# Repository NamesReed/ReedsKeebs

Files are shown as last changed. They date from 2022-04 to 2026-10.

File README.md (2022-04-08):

# ReedsKeebs
This repository contains all working firmware for my boards and design files I have made public.  

Join my discord for help: https://discord.gg/JtBQ8nmr7R

If you have a ProMicro or similar, you will find instructions for flashing within the Alish40 QMK Firmware directory.

# KMK firmware is officially supported on the KB2040, to change your keymap, you must edit a text file, this can be done on the fly and does not require reflashing.

If you have a KB2040 and an Alish board, you can find the QMK/Vial install guide within the QMK Firmware directory.

If you have a KB2040 and an Alish board, You can find the install guide within the KMK Firmware directory.  
### To boil it down simply, the QMK/Vial KB2040 firmware is experimental, and not officially supported. This grants you the use of changing your keymap with the Vial GUI. 
## Use QMK KB2040 at your own risk.

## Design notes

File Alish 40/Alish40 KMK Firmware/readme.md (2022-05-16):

## If you have a KB2040 and an Alish board, follow these instructions for installation of KMK firmware.

1. Plug KB2040 DIRECTLY into your computer, USB hubs can cause issues.
2. Download the CircuitPython installer, a .UF2 file, from https://circuitpython.org/board/adafruit_kb2040/
3. Enter Bootloader mode on the KB2040 by pressing and holding the BOOT button then pressing the RST button.
4. The KB2040 should reboot. You will then find it in your storage devices labeled RP2 BOOT / RPI-RP2.
5. Copy and paste the .UF2 file from earlier into the RPI-RP2 device.
6. The device should reboot and will appear in your storage devices as CIRCUITPY.
7. Download the kmk_firmware repository, found here: https://github.com/KMKfw/kmk_firmware by clicking the green "Code" button, and downloading the .zip.
8. Unzip the folder using your preferred program.
9. Drag the folder titled "kmk", NOT THE ENTIRE MASTER DIRECTORY, to the CIRCUITPY drive.
10. Drag the "boot.py" file to the CIRCUITPY drive.
11. Download this repository just like you did the kmk_firmware repo, and proceed to unzip the folder.
12. Drag the "main.py" file located within the AlishKMKFirmware folder to the CIRCUITPY drive, this should be on the same level as the boot.py file, not within the kmk folder.
13. Congratulations, you now have a fully functional KB2040.

Github won't allow me to just upload the files you need, so unfortunately you need to download the entire KMK repo.

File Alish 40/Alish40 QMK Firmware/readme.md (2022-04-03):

# Follow these instructions if you want a gui to change your keymap!

# Use the .hex if you have a pro micro, use the uf2 if you have a kb2040
Scroll to the bottom for KB2040 Vial firmware instructions

### This installation will provide you the ability to change your keymap on the fly without reflashing with the use of Vial, a VIA alternative.

1. Download this repository by going back to the main page, and clicking the green "Code" button, then downloading as .zip.
2. Unzip the file using whatever software you like, 7ZIP, WinRar, ect.
3. Download QMK Toolbox at this link, https://github.com/qmk/qmk_toolbox/releases 
4. Find the latest release, the file should look something like "qmk_toolbox.exe"
5. Now, plug your pro micro into your computer, DO NOT USE A USB HUB.
6. Find the reedskeebs_alish_vial.hex within QMK toolbox under the Local Files section.
7. Check the "Auto Flash" button.
8. Select the MCU as "atmega32u4" if it is not already.
9. At this point, QMK Toolbox should be properly configured, and look like this

9. Now, locate the RST and GND pins on the pro micro.



10. Short the RST and GND pins using a paperclip, tweezers, or something similiar.
11. This puts the Pro Micro into bootloader mode, and automatically starts flashing the firmware.
12. It should now look like this if flashed successfully 



13. If it did not flash, retry shorting the pins, sometimes it takes a few tries.
15. Congrats! You can now continue with the rest of the build.

## KB2040 Vial Firmware Instructions

If you have a KB2040 and would like Vial, read this guide

Download the Vial_Alish_KB2040 ONLY IF YOU HAVE A KB2040 Hold down the BOOT button on your KB2040, then press the Reset button. This puts the board into bootloader, you should see a new "drive" on your computer labeled something like "UF2 Bootloader" Drag the Vial_Alish_KB2040.uf2 file to the new drive.

Wait a few moments, now your KB2040 is flashed with Vial firmware, easily change your keymap by downloading the Vial gui.

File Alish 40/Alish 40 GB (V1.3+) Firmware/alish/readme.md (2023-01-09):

# reedskeebs/alish

reedskeebs/alish

*A short description of the keyboard/project*

* Keyboard Maintainer: [Kyle McCreery](https://github.com/kylemccreery)
* Hardware Supported: *The PCBs, controllers supported*
* Hardware Availability: *Links to where you can find this hardware*

Make example for this keyboard (after setting up your build environment):

    make reedskeebs/alish:default

Flashing example for this keyboard:

    make reedskeebs/alish:default:flash

See the [build environment setup](https://docs.qmk.fm/#/getting_started_build_tools) and the [make instructions](https://docs.qmk.fm/#/getting_started_make_guide) for more information. Brand new to QMK? Start with our [Complete Newbs Guide](https://docs.qmk.fm/#/newbs).

## Bootloader

Enter the bootloader in 3 ways:

* **Bootmagic reset**: Hold down the key at (0,0) in the matrix (usually the top left key or Escape) and plug in the keyboard
* **Physical reset button**: Briefly press the button on the back of the PCB - some may have pads you must short instead
* **Keycode in layout**: Press the key mapped to `RESET` if it is available

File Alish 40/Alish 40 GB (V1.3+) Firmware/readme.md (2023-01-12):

# Follow these instructions if you want a gui to change your keymap!

### This installation will provide you the ability to change your keymap on the fly without reflashing with the use of VIA.

Save the [reedskeebs_alish_via.hex](https://github.com/NamesReed/ReedsKeebs/raw/main/Alish%2040/Alish%2040%20GB%20(V1.3%2B)%20Firmware/reedskeebs_alish_via.hex) to your computer. Remember where you put it.

## Windows/MacOS
1. Download and install [the latest release of QMK Toolbox using this link](https://github.com/qmk/qmk_toolbox/releases).
2. Find the latest release, the file should look something like "qmk_toolbox.exe"
3. Now, plug your pro micro into your computer, DO NOT USE A USB HUB.
4. Find the reedskeebs_alish_via.hex within QMK toolbox under the Local Files section.
5. Check the "Auto Flash" button.
6. Select the MCU as "atmega32u4" if it is not already.
7. At this point, QMK Toolbox should be properly configured, and look like this

8. Now, locate the RST and GND pins on the pro micro.



9. Short the RST and GND pins using a paperclip, tweezers, or something similiar.
10. This puts the Pro Micro into bootloader mode, and automatically starts flashing the firmware.
11. It should now look like this if flashed successfully 



12. If it did not flash, retry shorting the pins, sometimes it takes a few tries.
## Linux
1. Follow steps 2 and 3 of [the QMK setup instructions linked here](https://docs.qmk.fm/#/newbs_getting_started) to install all prerequisites and flashing tools.
2. Plug your pro micro into your computer, DO NOT USE A USB HUB.
3. Run the command `qmk flash /path/to/reedskeebs_alish_via.hex`.
4. When prompted, short the RST and GND pins using a paperclip, tweezers, or something similiar.

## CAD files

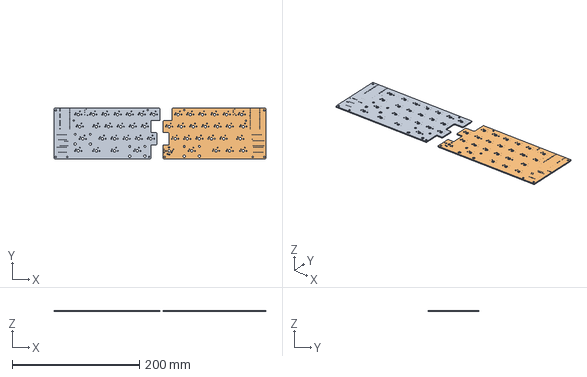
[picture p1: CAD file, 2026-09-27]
Diomedes/Cad Files/Diomedes Full.step
333.4 x 79.8 x 1.51 mm
Diomedes Full-unsaved-export-oQOao5_PCB_1
Diomedes Full-unsaved-export-oQOao5_PCB_2

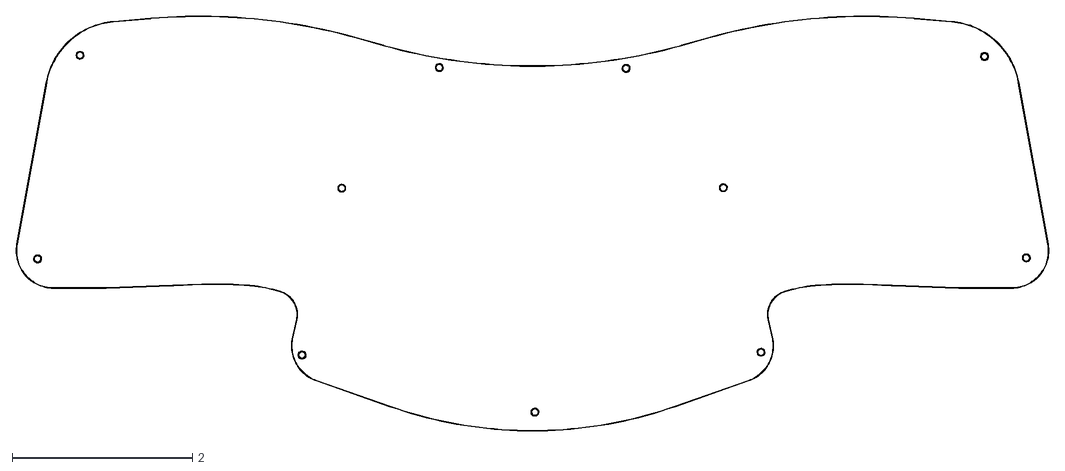
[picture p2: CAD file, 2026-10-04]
Waxwing/Waxwing Prod Files/DXF's/Waxwing_Bottom.dxf
11.5 x 4.60

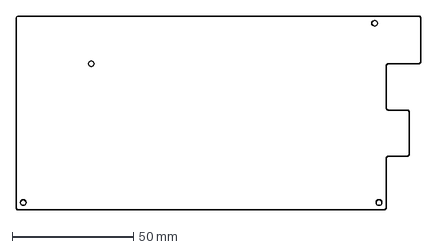
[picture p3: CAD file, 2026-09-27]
Diomedes/Cad Files/DiomedesBottomL.dxf
166.7 x 79.8 mm

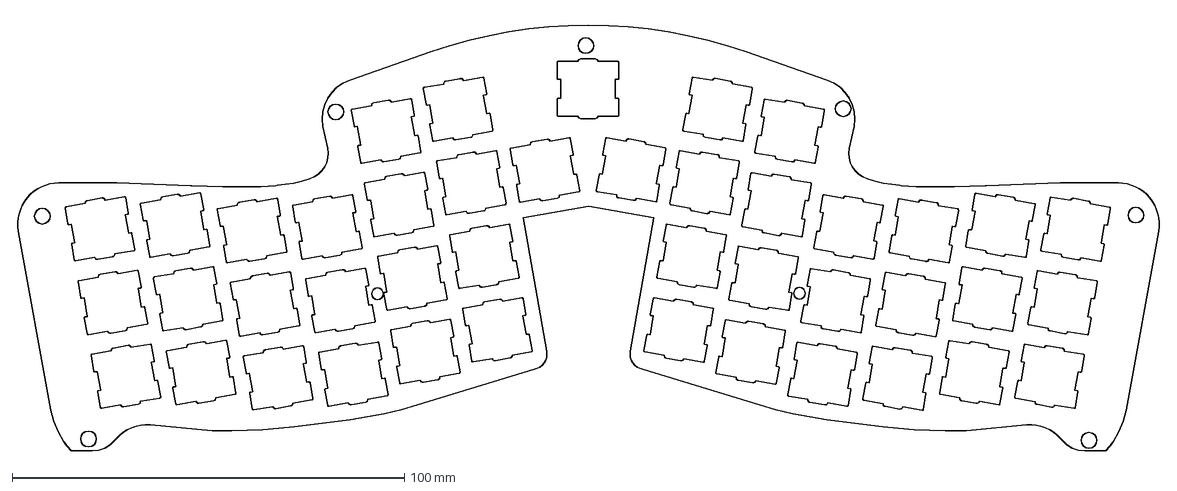
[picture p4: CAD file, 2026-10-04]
Waxwing/Waxwing Prod Files/DXF's/Waxwing_Plate_V3.dxf
291.8 x 110.8 mm

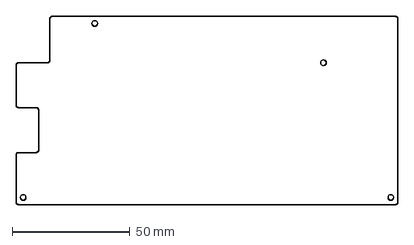
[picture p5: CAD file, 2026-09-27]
Diomedes/Cad Files/DiomedesBottomR.dxf
161.9 x 79.8 mm

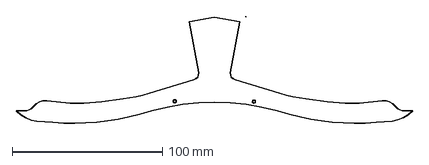
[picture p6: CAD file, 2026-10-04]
Waxwing/Waxwing Prod Files/DXF's/Waxwing_Window_V1.dxf
263.9 x 72.4 mm

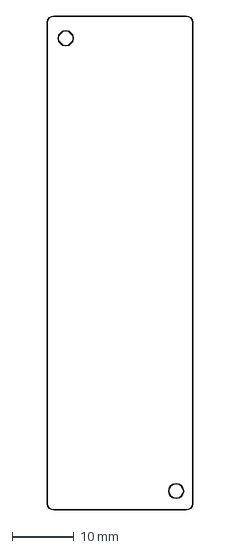
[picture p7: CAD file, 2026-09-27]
Diomedes/Cad Files/Diomedes Window.dxf
23.5 x 79.8 mm

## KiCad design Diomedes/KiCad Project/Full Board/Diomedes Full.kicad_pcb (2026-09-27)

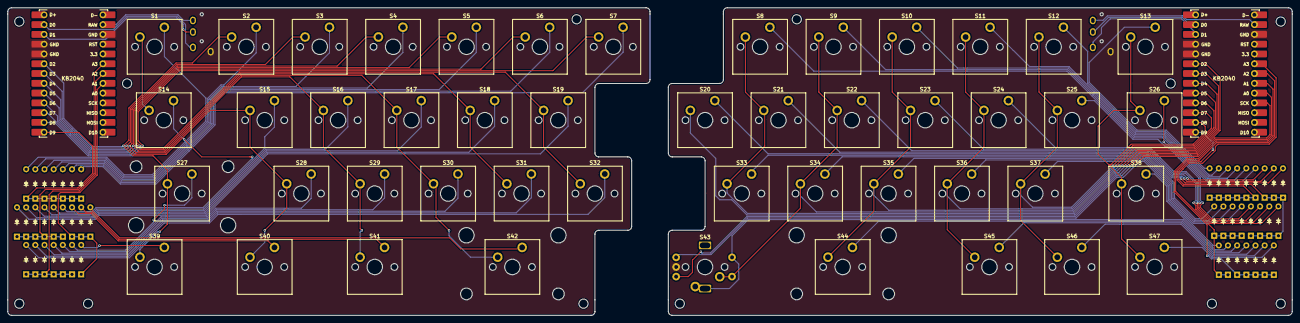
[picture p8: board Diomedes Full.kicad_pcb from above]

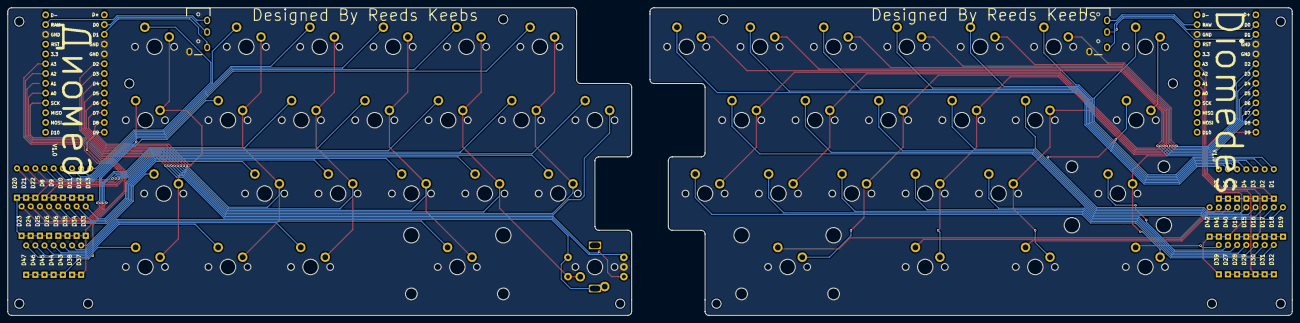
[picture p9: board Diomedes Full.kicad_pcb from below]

Board: 2 copper layers, 333.4 x 79.8 mm, 101 parts (2 on the bottom side), 78 nets.

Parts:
D1, D2, D3, D4, D5, D6, D7, D8, D9, D10, D11, D12, D13, D14, D15, D16, D17, D18, D19, D20, D21, D22, D23, D24, D25, D26, D27, D28, D29, D30, D31, D32, D33, D34, D35, D36, D37, D38, D39, D40, D41, D42, D43, D44, D45, D46, D47: Diode_DO-35
MC1, MC2: Adafruit_KB2040_SMD
S1, S13, S39, S40, S41: MX_PCB_1.50u
S2, S3, S4, S5, S6, S7, S8, S9, S10, S11, S12, S15, S16, S17, S18, S19, S20, S21, S22, S23, S24, S25, S28, S29, S30, S31, S32, S33, S34, S35, S36, S37, S46: MX_PCB_1.00u
S14, S38: MX_PCB_1.75u
S26, S45, S47: MX_PCB_1.25u
S27, S42: MX_PCB_2.25u
S43: RotaryEncoder_Switch; Encoder_EC11_MX_Combo
S44: MX_PCB_2.75u
STAB1, STAB2, STAB3: Stabilizer_MX_2.00u
T1, T2: TRRS; 4Pole-TRRS-PJ-320A

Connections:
/Col 1: MC1.6 (2/PD1), S1.1, S14.1, S27.1, S39.1
/Col 1B: MC2.6 (2/PD1), S20.1
/Col 2: MC1.7 (3/PD0), S2.1, S15.1, S28.1, S40.1
/Col 2B: MC2.7 (3/PD0), S8.1, S21.1, S33.1
/Col 3: MC1.8 (4/PD4), S3.1, S16.1, S29.1, S41.1
/Col 3B: MC2.8 (4/PD4), S9.1, S22.1, S34.1, S43.S1
/Col 4: MC1.9 (5/PC6), S4.1, S17.1, S30.1, S42.1
/Col 4B: MC2.9 (5/PC6), S10.1, S23.1, S35.1, S44.1
/Col 5: MC1.10 (6/PD7), S5.1, S18.1, S31.1
/Col 5B: MC2.10 (6/PD7), S11.1, S24.1, S36.1, S45.1
/Col 6: MC1.11 (7/PE6), S6.1, S19.1, S32.1
/Col 6B: MC2.11 (7/PE6), S12.1, S25.1, S37.1, S46.1
/Col 7: MC1.12 (8/PB4), S7.1
/Col 7B: MC2.12 (8/PB4), S13.1, S26.1, S38.1, S47.1
/ENC_A: MC2.22 (A0/PF7), S43.A
/ENC_B: MC2.23 (15/PB1), S43.B
/RAW_L: MC1.15 (RAW), T1.4 (RING2)
/RAW_R: MC2.15 (RAW), T2.4 (RING2)
/RX_L: MC1.3 (RX1/PD2), T1.3 (RING1)
/RX_R: MC2.2 (TX0/PD3), T2.3 (RING1)
/Row 1: D1.1 (K), D2.1 (K), D3.1 (K), D4.1 (K), D5.1 (K), D6.1 (K), D7.1 (K), MC1.13 (9/PB5)
/Row 1B: D8.1 (K), D9.1 (K), D10.1 (K), D11.1 (K), D12.1 (K), D13.1 (K), MC2.13 (9/PB5)
/Row 2: D14.1 (K), D15.1 (K), D16.1 (K), D17.1 (K), D18.1 (K), D19.1 (K), MC1.19 (A3/PF4)
/Row 2B: D20.1 (K), D21.1 (K), D22.1 (K), D23.1 (K), D24.1 (K), D25.1 (K), D26.1 (K), MC2.19 (A3/PF4)
/Row 3: D27.1 (K), D28.1 (K), D29.1 (K), D30.1 (K), D31.1 (K), D32.1 (K), MC1.20 (A2/PF5)
/Row 3B: D33.1 (K), D34.1 (K), D35.1 (K), D36.1 (K), D37.1 (K), D38.1 (K), MC2.20 (A2/PF5)
/Row 4: D39.1 (K), D40.1 (K), D41.1 (K), D42.1 (K), MC1.21 (A1/PF6)
/Row 4B: D43.1 (K), D44.1 (K), D45.1 (K), D46.1 (K), D47.1 (K), MC2.21 (A1/PF6)
/TX_L: MC1.2 (TX0/PD3), T1.2 (TIP)
/TX_R: MC2.3 (RX1/PD2), T2.2 (TIP)
GND: MC1.4 (GND), MC1.5 (GND), MC1.16 (GND), MC2.4 (GND), MC2.5 (GND), MC2.16 (GND), S43.C, T1.1 (SLEEVE), T2.1 (SLEEVE)
unnamed: D1.2 (A), S1.2
unnamed: D2.2 (A), S2.2
unnamed: D3.2 (A), S3.2
unnamed: D4.2 (A), S4.2
unnamed: D5.2 (A), S5.2
unnamed: D6.2 (A), S6.2
unnamed: D7.2 (A), S7.2
unnamed: D8.2 (A), S8.2
unnamed: D9.2 (A), S9.2
unnamed: D10.2 (A), S10.2
unnamed: D11.2 (A), S11.2
unnamed: D12.2 (A), S12.2
unnamed: D13.2 (A), S13.2
unnamed: D14.2 (A), S14.2
unnamed: D15.2 (A), S15.2
unnamed: D16.2 (A), S16.2
unnamed: D17.2 (A), S17.2
unnamed: D18.2 (A), S18.2
unnamed: D19.2 (A), S19.2
unnamed: D20.2 (A), S20.2
unnamed: D21.2 (A), S21.2
unnamed: D22.2 (A), S22.2
unnamed: D23.2 (A), S23.2
unnamed: D24.2 (A), S24.2
unnamed: D25.2 (A), S25.2
unnamed: D26.2 (A), S26.2
unnamed: D27.2 (A), S27.2
unnamed: D28.2 (A), S28.2
unnamed: D29.2 (A), S29.2
unnamed: D30.2 (A), S30.2
unnamed: D31.2 (A), S31.2
unnamed: D32.2 (A), S32.2
unnamed: D33.2 (A), S33.2
unnamed: D34.2 (A), S34.2
unnamed: D35.2 (A), S35.2
unnamed: D36.2 (A), S36.2
unnamed: D37.2 (A), S37.2
unnamed: D38.2 (A), S38.2
unnamed: D39.2 (A), S39.2
unnamed: D40.2 (A), S40.2
unnamed: D41.2 (A), S41.2
unnamed: D42.2 (A), S42.2
unnamed: D43.2 (A), S43.S2
unnamed: D44.2 (A), S44.2
unnamed: D45.2 (A), S45.2
unnamed: D46.2 (A), S46.2
unnamed: D47.2 (A), S47.2

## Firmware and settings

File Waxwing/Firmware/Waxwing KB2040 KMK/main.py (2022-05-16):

import board

from kmk.kmk_keyboard import KMKKeyboard
from kmk.keys import KC
from kmk.scanners import DiodeOrientation
from kmk.modules.layers import Layers



keyboard = KMKKeyboard()
layers_ext = Layers()

keyboard.modules = [layers_ext]


from kmk.extensions.rgb import RGB


rgb_ext = RGB(pixel_pin=board.A3, num_pixels=4)
keyboard.extensions.append(rgb_ext)


#Waxwing Pins for KB2040
keyboard.col_pins = (board.D4, board.D5, board.D6, board.D7, board.D8, board.D9, board.A2, board.D10, board.MOSI, board.MISO, board.SCK, board.A0, board.A1)
keyboard.row_pins = (board.D3, board.D2, board.D1, board.D0)
keyboard.diode_orientation = DiodeOrientation.COL2ROW

keyboard.keymap = [
    [#QWERTY
        KC.TAB, KC.Q, KC.W, KC.E, KC.R, KC.T, KC.NO, KC.Y, KC.U, KC.I, KC.O, KC.P, KC.BSPC, 
	    KC.MO(2), KC.A, KC.S, KC.D, KC.F, KC.G, KC.B, KC.H, KC.J, KC.K, KC.L, KC.QUOT, KC.ENT, 
	    KC.LSFT, KC.LCTRL, KC.Z, KC.X, KC.C, KC.V, KC.MO(1), KC.N, KC.M, KC.COMM, KC.DOT, KC.SLASH, KC.RSFT, 
	    KC.NO, KC.NO, KC.NO, KC.NO, KC.LCTRL, KC.LALT, KC.MO(1), KC.SPC, KC.RCTRL, KC.NO, KC.NO, KC.NO, KC.NO
    ],
    [#Number Layer
        KC.ESC, KC.N1, KC.N2, KC.N3, KC.N4, KC.N5, KC.NO, KC.N6, KC.N7, KC.N8, KC.N9, KC.N0, KC.BSPC, 
	    KC.DEL, KC.RGB_TOG, KC.RGB_HUI, KC.RGB_HUD, KC.RGB_VAI, KC.RGB_VAD, KC.TRNS, KC.LBRC, KC.RBRC, KC.MINUS, KC.EQUAL, KC.QUOT, KC.SCLN, 
	    KC.TRNS, KC.TRNS, KC.RGB_SAI, KC.RGB_SAD, KC.TRNS, KC.TRNS, KC.TRNS, KC.TRNS, KC.TRNS, KC.TRNS, KC.TRNS, KC.TRNS, KC.TRNS, 
	    KC.NO, KC.NO, KC.NO, KC.NO, KC.LCTRL, KC.LALT, KC.SPC, KC.RALT, KC.RCTRL, KC.NO, KC.NO, KC.NO, KC.NO
    ],

    [#Function Layer
        KC.ESC, KC.F1, KC.UP, KC.F3, KC.F4, KC.F5, KC.NO, KC.F6, KC.F7, KC.F8, KC.F9, KC.F10, KC.BSPC, 
	    KC.TRNS, KC.LEFT, KC.DOWN, KC.RIGHT, KC.TRNS, KC.TRNS, KC.TRNS, KC.TRNS, KC.TRNS, KC.TRNS, KC.TRNS, KC.QUOT, KC.ENT, 
	    KC.TRNS, KC.TRNS, KC.TRNS, KC.TRNS, KC.TRNS, KC.TRNS, KC.TRNS, KC.TRNS, KC.TRNS, KC.TRNS, KC.TRNS, KC.TRNS, KC.TRNS, 
	    KC.NO, KC.NO, KC.NO, KC.NO, KC.LCTRL, KC.LALT, KC.SPC, KC.VOLD, KC.VOLU, KC.NO, KC.NO, KC.NO, KC.NO
    ],
]

if __name__ == '__main__':
    keyboard.go() 

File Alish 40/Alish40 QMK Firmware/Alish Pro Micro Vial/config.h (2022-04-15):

#ifndef CONFIG_H
#define CONFIG_H

#include "config_common.h"

/* USB Device descriptor parameter */
#define VENDOR_ID       0xFEED 
#define PRODUCT_ID      0x3180
#define DEVICE_VER      0x0001
#define MANUFACTURER    ReedsKeebs
#define PRODUCT         Alish40
#define DESCRIPTION     Keyboard

/* key matrix size */
#define MATRIX_ROWS 4
#define MATRIX_COLS 12

/* key matrix pins */
#define MATRIX_ROW_PINS { F6, F7, B1, B3 }
#define MATRIX_COL_PINS { D3, D2, D1, D0, D4, C6, B6, B2, B5, B4, E6, D7 }
#define UNUSED_PINS

/*encoder pins*/
#define ENCODERS_PAD_A { F4 }
#define ENCODERS_PAD_B { F5 }

/*encoder settings*/
#define ENCODER_RESOLUTION 4

/* COL2ROW or ROW2COL */
#define DIODE_DIRECTION COL2ROW

/* Set 0 if debouncing isn't needed */
#define DEBOUNCING_DELAY 5

/* Mechanical locking support. Use KC_LCAP, KC_LNUM or KC_LSCR instead in keymap */
#define LOCKING_SUPPORT_ENABLE

/* Locking resynchronize hack */
#define LOCKING_RESYNC_ENABLE

/* key combination for command */
#define IS_COMMAND() ( \
    keyboard_report->mods == (MOD_BIT(KC_LSHIFT) | MOD_BIT(KC_RSHIFT)) \
)

/* prevent stuck modifiers */
#define PREVENT_STUCK_MODIFIERS


#ifdef RGB_DI_PIN
#define RGBLIGHT_ANIMATIONS
#define RGBLED_NUM 0
#define RGBLIGHT_HUE_STEP 8
#define RGBLIGHT_SAT_STEP 8
#define RGBLIGHT_VAL_STEP 8
#endif

#endif

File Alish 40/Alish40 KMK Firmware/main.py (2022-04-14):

import board

from kmk.kmk_keyboard import KMKKeyboard
from kmk.keys import KC
from kmk.scanners import DiodeOrientation
from kmk.modules.layers import Layers
from kmk.modules.encoder import EncoderHandler

encoder_handler = EncoderHandler()

keyboard = KMKKeyboard()

layers_ext = Layers()

keyboard.modules = [layers_ext, encoder_handler]

#Alish Pins for KB2040
keyboard.col_pins = (board.D0, board.D1, board.D2, board.D3, board.D4, board.D5, board.D10, board.MOSI, board.D9, board.D8, board.D7, board.D6)
keyboard.row_pins = (board.A1, board.A0, board.SCK, board.MISO)
keyboard.diode_orientation = DiodeOrientation.COL2ROW

#Alish Encoder Pins for KB2040
encoder_handler.pins = ((board.A3, board.A2, board.SDA, False),)


keyboard.keymap = [
    [#QWERTY
        KC.TAB, KC.Q, KC.W, KC.E, KC.R, KC.T, KC.Y, KC.U, KC.I, KC.O, KC.P, KC.BSPC, 
	    KC.MO(2), KC.A, KC.S, KC.D, KC.F, KC.G, KC.H, KC.J, KC.K, KC.L, KC.QUOT, KC.ENT, 
	    KC.LSFT, KC.Z, KC.X, KC.C, KC.V, KC.B, KC.B, KC.N, KC.M, KC.COMM, KC.DOT, KC.RSFT, 
	    KC.LCTL, KC.TG(3), KC.LALT, KC.NO, KC.MO(1), KC.NO, KC.NO, KC.SPC, KC.NO, KC.LCTL, KC.LEFT, KC.RGHT,
    ],
    [#Number Layer
        KC.ESC, KC.N1, KC.N2, KC.N3, KC.N4, KC.N5, KC.N6, KC.N7, KC.N8, KC.N9, KC.N0, KC.BSPC, 
	    KC.DEL, KC.TRNS, KC.TRNS, KC.TRNS, KC.TRNS, KC.TRNS, KC.TRNS, KC.EQL, KC.MINS, KC.LBRC, KC.RBRC, KC.SCLN, 
	    KC.TRNS, KC.TRNS, KC.TRNS, KC.TRNS, KC.TRNS, KC.TRNS, KC.TRNS, KC.TRNS, KC.TRNS, KC.TRNS, KC.SLASH, KC.TRNS, 
	    KC.LCTL, KC.TRNS, KC.LALT, KC.NO, KC.TRNS, KC.NO, KC.SPC, KC.NO, KC.LCTL, KC.LEFT, KC.RGHT,
    ],
    [#Function Layer
        KC.ESC, KC.F1, KC.F2, KC.F3, KC.F4, KC.F5, KC.F6, KC.F7, KC.F8, KC.F9, KC.F10, KC.F11, 
	    KC.TRNS, KC.TRNS, KC.TRNS, KC.TRNS, KC.TRNS, KC.TRNS, KC.TRNS, KC.TRNS, KC.TRNS, KC.TRNS, KC.TRNS, KC.TRNS, 
	    KC.TRNS, KC.TRNS, KC.TRNS, KC.TRNS, KC.TRNS, KC.TRNS, KC.TRNS, KC.TRNS, KC.TRNS, KC.TRNS, KC.TRNS, KC.TRNS, 
	    KC.LCTL, KC.TRNS, KC.LALT, KC.NO, KC.TRNS, KC.NO, KC.NO, KC.SPC, KC.NO, KC.LCTL, KC.LEFT, KC.RGHT,
    ],
    [#Gaming Layer (Left and right space)
        KC.TAB, KC.Q, KC.W, KC.E, KC.R, KC.T, KC.Y, KC.U, KC.I, KC.O, KC.P, KC.BSPC, 
	    KC.CAPS, KC.A, KC.S, KC.D, KC.F, KC.G, KC.H, KC.J, KC.K, KC.L, KC.QUOT, KC.ENT, 
	    KC.LSFT, KC.Z, KC.X, KC.C, KC.V, KC.B, KC.B, KC.N, KC.M, KC.COMM, KC.DOT, KC.RSFT, 
	    KC.LCTL, KC.TRNS, KC.LALT, KC.NO, KC.SPC, KC.NO, KC.NO, KC.SPC, KC.NO, KC.LCTL, KC.LEFT, KC.RGHT,
    ]
]

encoder_handler.map = ( ((KC.VOLD, KC.VOLU, KC.MUTE),), 
                        ((KC.DOWN, KC.UP, KC.MUTE),), 
                        ((KC.VOLD, KC.VOLU, KC.N1),), 
                        ((KC.VOLD, KC.VOLU, KC.N1),), 
                        )

if __name__ == '__main__':
    keyboard.go()

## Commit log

2022-03-13 Deleted directory, troubleshooting resolved
    [config.h]
2022-03-13 Added Vial Hex for Pro Micro boards
2022-03-26 Added updated precompiled vial firmware.
    Included encoder, and split/big enter layout options.
2022-04-03 Replaced code.py with main.py
    improved default keymap, fixed encoder pins and direction.
    [main.py]
2026-09-27 Add Diomedes
    Initial commit for Diomedes, I'm out of practice, I'm sure something on the firmware side of things is messed up.
    [Diomedes Full.kicad_pcb, Diomedes Full.kicad_sch, Diomedes Full.step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]
2026-09-27 s
    s
    [Diomedes Full.kicad_pcb, Diomedes Full.kicad_sch, Diomedes Full.step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]
2026-10-04 Restructured, added waxwing files
    Added waxwing files, restructured to make navigation easier
    [AirShip-rounded-B_Cu.gbl, AirShip-rounded-B_Mask.gbs, AirShip-rounded-B_Paste.gbp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]
